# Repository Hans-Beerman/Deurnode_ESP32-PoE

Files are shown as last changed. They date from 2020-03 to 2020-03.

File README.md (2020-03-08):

**KiCaD (concept) design Deurnode nieuw**

Current version: concept V0.8

This repository contains the KiCad design for Deurnode nieuw, a deurnode for the Makerspace Leiden. This new design is based on the use of an Olimex ESP32-PoE.

**This Deurnode Nieuw has the following features:**

- Two digital inputs van be used. The following options are available:
	Option 1:
 	- 1x Simple digital switch input (to be used for the Grote Schakelaar e.g.).
 	- 1x Opto coupler input.
	Remark:
	If input Schakelaar is not used, C1 could be removed

	Option 2:
  - 2x opto coupler input.

	Both opto couplers can detect 230V AC available or not. By changing the input resistors of the optocouplers the inputs can be used for other voltages as well.

- 1 digital output is available. The following options are available:
  - Digital output, to directly control a buzzer.
  - Digital output to switch a coil or so. There are two options:
    - A relais controlled isolated output (max. 250V AC/10A).
    - A FET based output using the 12V power from an external power supply.
	The FET can handle max DC 55V/30 A. In our case max Ids is much less, due to to low maximum gateway voltage of about 3V. In case it is needed, the FET can be kept cool by means of a small cool block.
	For testing purposes, both the relais and the FET can be switched on permanently by placing jumper "Rel./FET Override".

- SPI based RFID reader connection..

- Step motor output, based on Polu Breakout A4988.

**Power supply:**

Depending on how the deurnode is used, there are two options to provide power to the deurnode print:

1. The ethernet port of the Olimex ESP32-PoE board is directly connected to the MSL LAN. Jumper J19 (Use external 12V) must be removed in this situation. In that case there is no 12V available. It is however possible to provide 12V with an external PSU. Without external 12 V the step motor and the buzzer will not function at all and also the 12V output for the FET will not be available.
2. To power the board via an external PSU (only). J19 must be installed and the ethernet board of the Olimex board should not be connected to a PoE switch port.

The following solution is available to couple the deurnode directly to a PoE connection of MSL LAN and also provide 12V to the deurnode board. See the diagram in the file &quot;Deurnode Nieuw power supply V0.1 20200302.pdf&quot;

For this solution a PoE splitter is used. On the Deurnode board jumper J19 must be installed.

**Protection 230V circuits for the opto couplers**

To prevent hazardous shocks, a plexiglass plate can be mounted on the board. The board contains 3 holes to mount a plate.

For more information about these protection plates, see the &quot;DeurnodeProtection-230V V0.2 20200308.pdf&quot; or the Autocad &quot;DeurnodeProtection-230V.dwg&quot; files.

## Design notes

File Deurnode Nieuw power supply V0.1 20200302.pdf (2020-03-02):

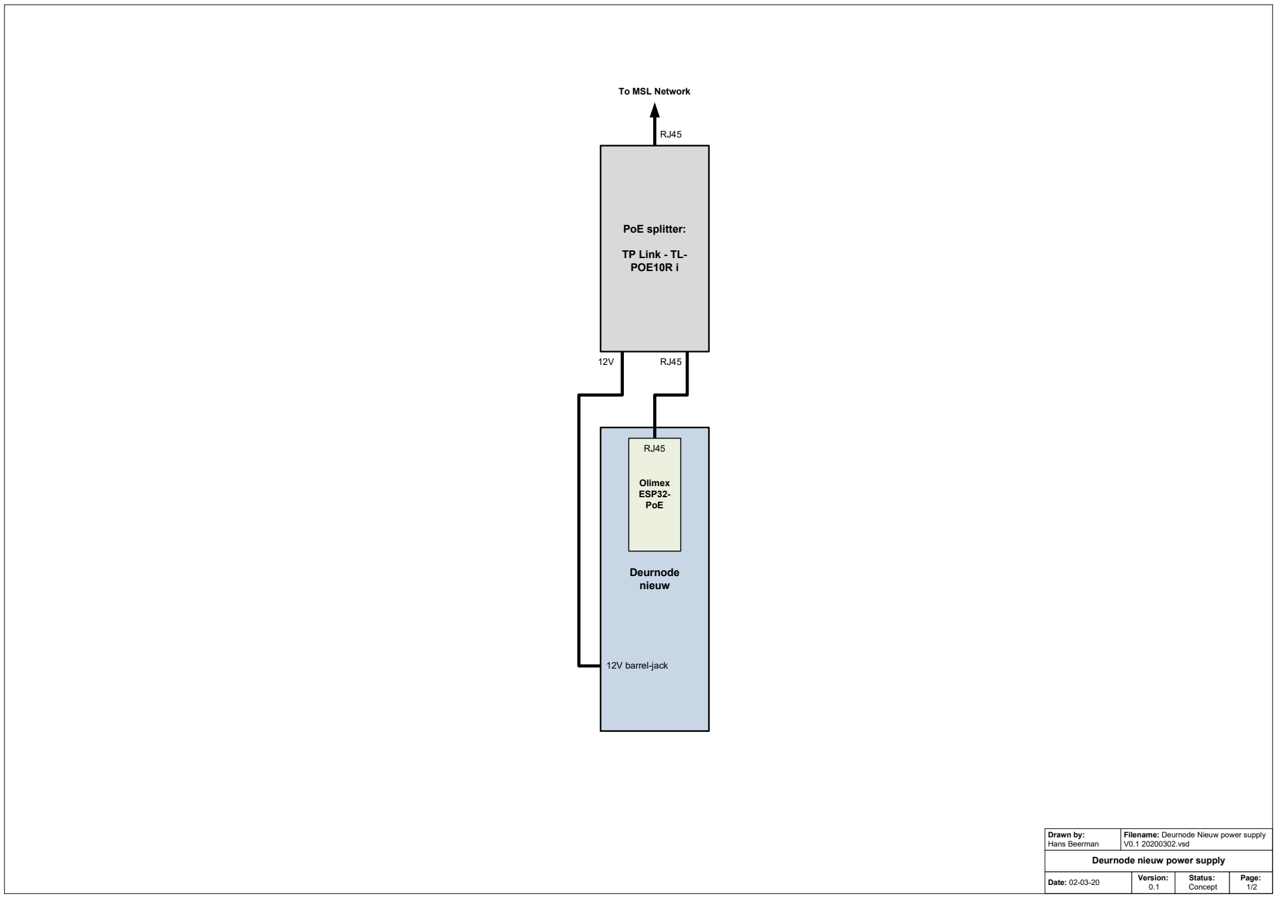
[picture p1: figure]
Deurnode nieuw power supply; Filename: Deurnode Nieuw power supply V0.1 20200302.vsd; Date: 02-03-20; Page:; Drawn by: Hans Beerman; Status: Concept; Version: 0.1; To MSL Network; Deurnode nieuw; Olimex ESP32- PoE; PoE splitter:; TP Link - TL- POE10R i; 12V barrel-jack

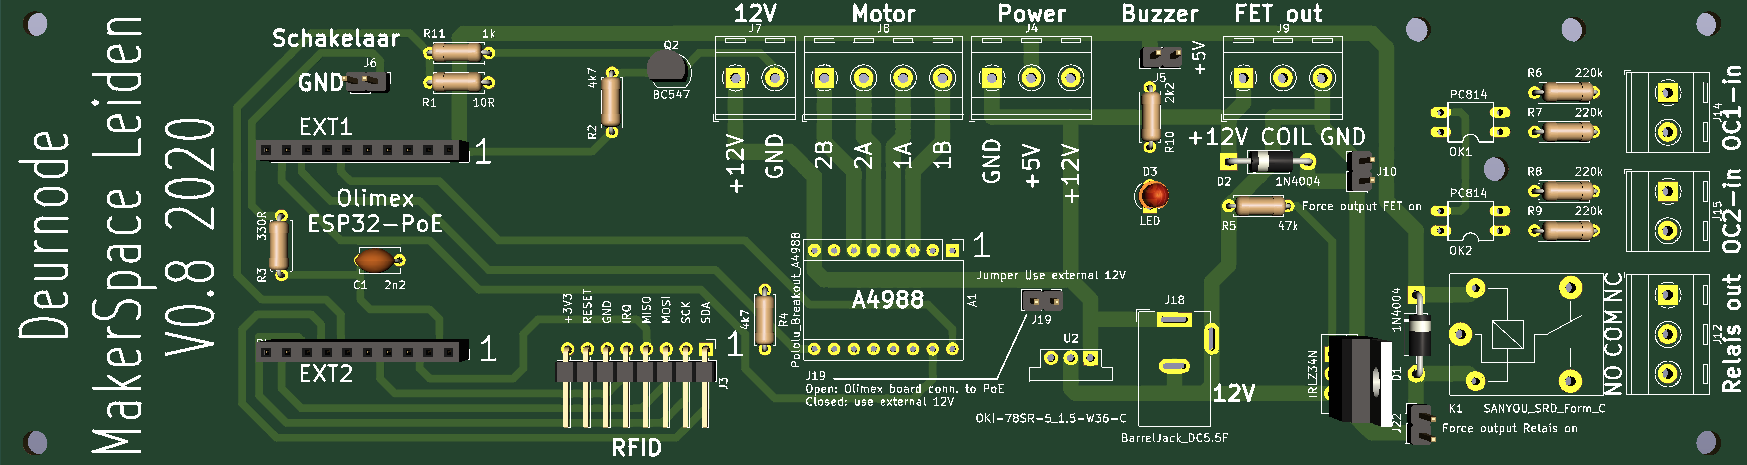
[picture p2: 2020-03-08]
Deurnode nieuw.png

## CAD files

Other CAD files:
DeurnodeProtection-230V V0.2 20200308.dwg

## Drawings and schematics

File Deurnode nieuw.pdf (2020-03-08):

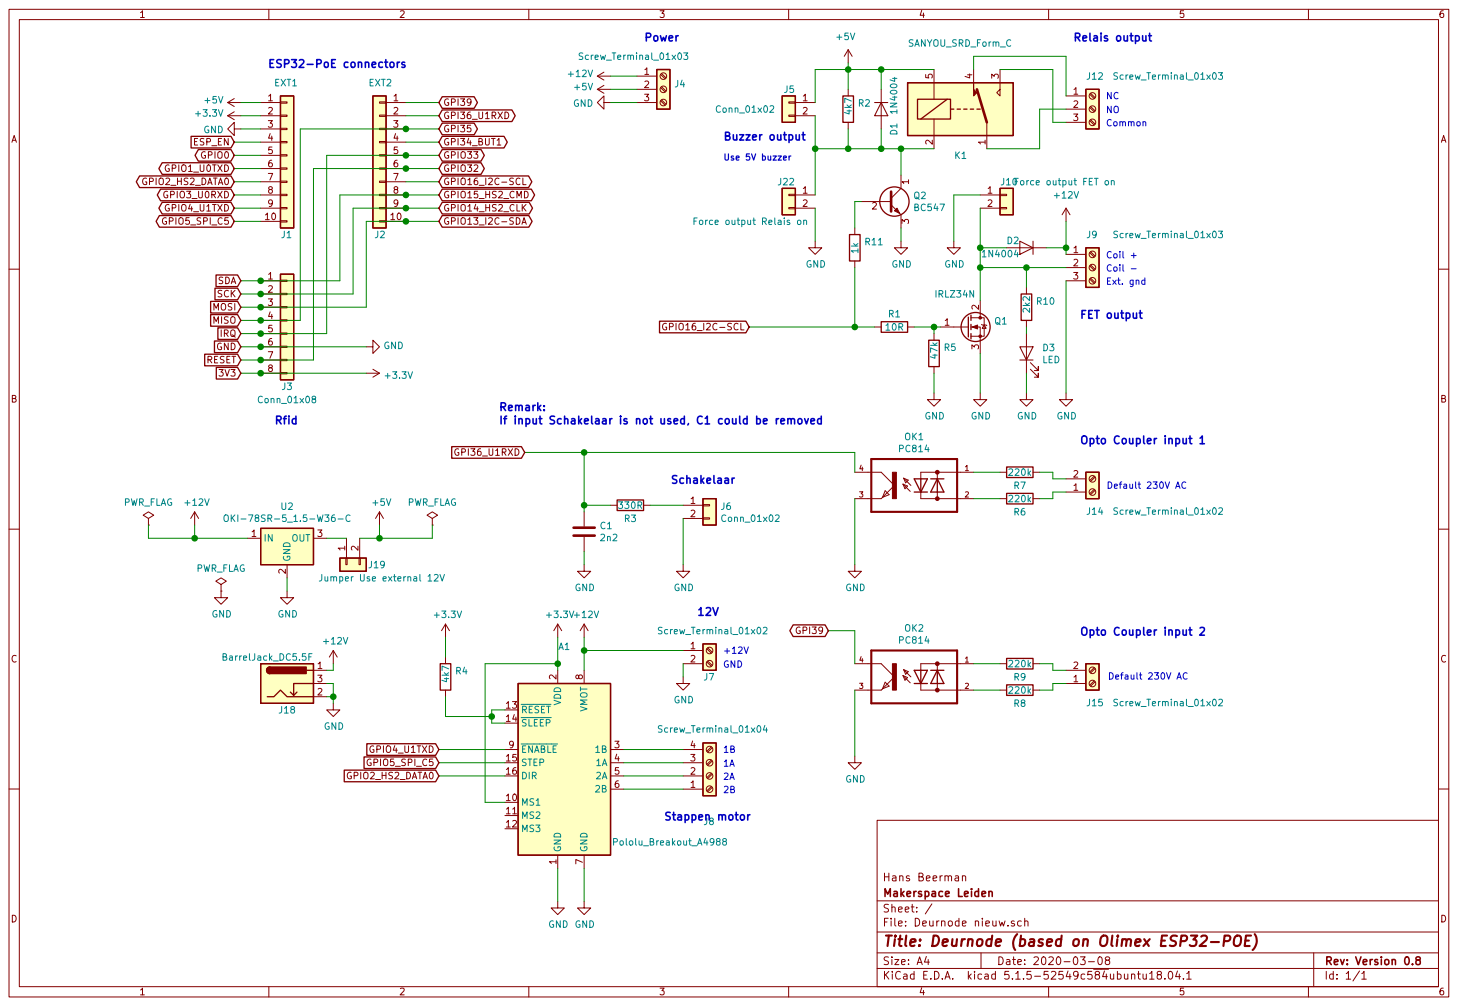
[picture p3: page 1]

J10 Force output FET on
Ext. gnd Default 230V AC

If input Schakelaar is not used, C1 could be removed

Id: 1/1 Title: Deurnode (based on Olimex ESP32-POE) File: Deurnode nieuw.sch Sheet: / Makerspace Leiden Hans Beerman R3

1 MS1 10 MS2 11 MS3 12 RESET 13 SLEEP 14 STEP 15 DIR 16 VDD

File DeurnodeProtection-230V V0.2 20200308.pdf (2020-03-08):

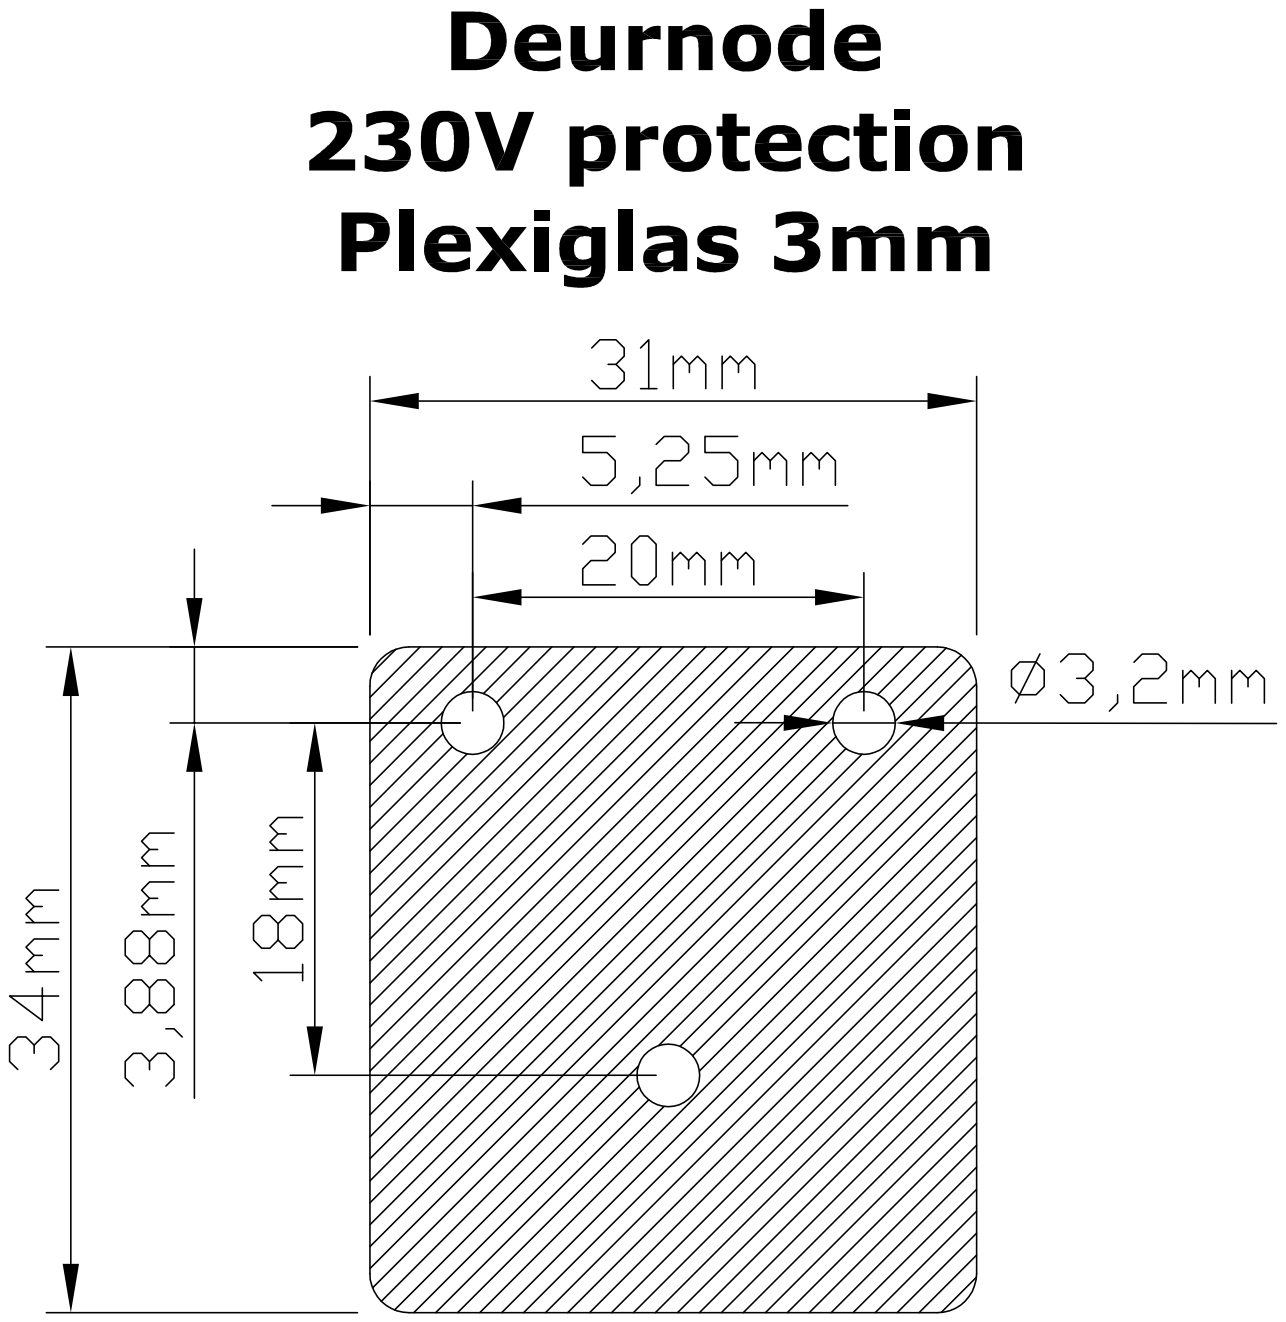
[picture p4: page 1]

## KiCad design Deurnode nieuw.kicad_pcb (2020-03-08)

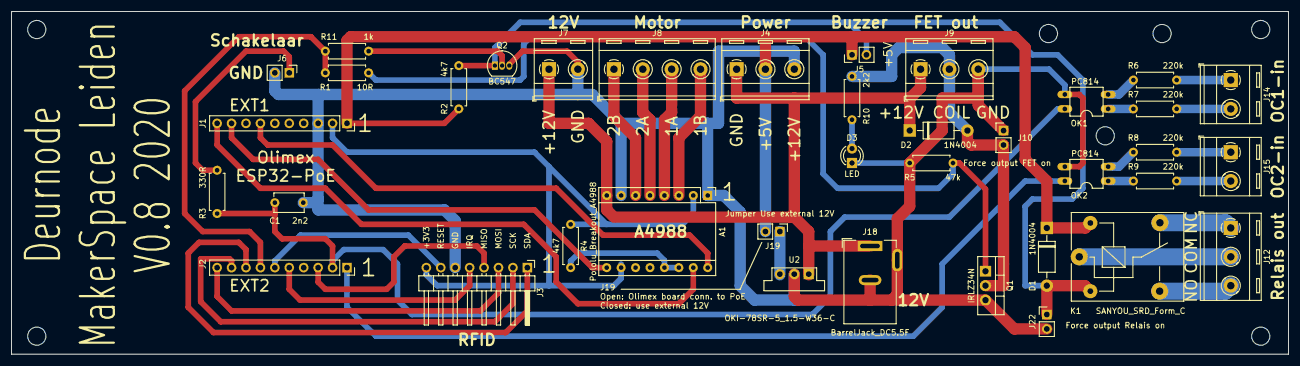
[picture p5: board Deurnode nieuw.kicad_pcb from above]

Board: 2 copper layers, 224.8 x 60.3 mm, 38 parts (0 on the bottom side), 39 nets.

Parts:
A1: Pololu_Breakout_A4988; Pololu_Breakout-16_15.2x20.3mm
C1: 2n2; C_Disc_D5.1mm_W3.2mm_P5.00mm
D1, D2: 1N4004; D_DO-41_SOD81_P10.16mm_Horizontal
D3: LED; LED_D3.0mm
J1: EXT1; PinSocket_1x10_P2.54mm_Vertical
J2: EXT2; PinSocket_1x10_P2.54mm_Vertical
J3: Conn_01x08; PinHeader_1x08_P2.54mm_Horizontal
J4, J9, J12: Screw_Terminal_01x03; TerminalBlock_RND_205-00288_1x03_P5.08mm_Horizontal
J5, J6: Conn_01x02; PinHeader_1x02_P2.54mm_Vertical
J7, J14, J15: Screw_Terminal_01x02; TerminalBlock_RND_205-00287_1x02_P5.08mm_Horizontal
J8: Screw_Terminal_01x04; TerminalBlock_RND_205-00289_1x04_P5.08mm_Horizontal
J10: Force output FET on; PinHeader_1x02_P2.54mm_Vertical
J18: BarrelJack_DC5.5F
J19: Jumper Use external 12V; PinHeader_1x02_P2.54mm_Vertical
J22: Force output Relais on; PinHeader_1x02_P2.54mm_Vertical
K1: SANYOU_SRD_Form_C; Relay_SPDT_SANYOU_SRD_Series_Form_C
OK1, OK2: PC814; DIL04
Q1: IRLZ34N; TO-220-3_Vertical
Q2: BC547; TO-92_Inline
R1: 10R; R_Axial_DIN0207_L6.3mm_D2.5mm_P7.62mm_Horizontal
R2, R4: 4k7; R_Axial_DIN0207_L6.3mm_D2.5mm_P7.62mm_Horizontal
R3: 330R; R_Axial_DIN0207_L6.3mm_D2.5mm_P7.62mm_Horizontal
R5: 47k; R_Axial_DIN0207_L6.3mm_D2.5mm_P7.62mm_Horizontal
R6, R7, R8, R9: 220k; R_Axial_DIN0207_L6.3mm_D2.5mm_P7.62mm_Horizontal
R10: 2k2; R_Axial_DIN0207_L6.3mm_D2.5mm_P7.62mm_Horizontal
R11: 1k; R_Axial_DIN0207_L6.3mm_D2.5mm_P7.62mm_Horizontal
U2: OKI-78SR-5_1.5-W36-C; Converter_DCDC_muRata_OKI-78SR_Vertical

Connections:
3V3: A1.2, A1.10, J1.2, J3.8, R4.1
+5V: D1.1, J1.1, J4.2, J5.1, J19.2, K1.5, R2.1
+12V: A1.8, D2.1, J4.1, J7.1, J9.1, J18.1, U2.1
GND: A1.1, A1.7, C1.2, D3.1, J1.3, J3.6, J4.3, J6.2, J7.2, J9.3, J10.1, J18.2, J18.3, J22.2, OK1.3, OK2.3, Q1.3, Q2.3, R5.2, U2.2
GPI35: J2.3, J3.4
GPI36_U1RXD: C1.1, J2.2, OK1.4, R3.2
GPI39: J2.1, OK2.4
GPIO2_HS2_DATA0: A1.16, J1.7
GPIO4_U1TXD: A1.9, J1.9
GPIO5_SPI_C5: A1.15, J1.10
GPIO13_I2C-SDA: J2.10, J3.3
GPIO14_HS2_CLK: J2.9, J3.2
GPIO15_HS2_CMD: J2.8, J3.1
GPIO16_I2C-SCL: J2.7, R1.2, R11.2
GPIO32: J2.6, J3.7
GPIO33: J2.5, J3.5
unnamed: A1.3, J8.4
unnamed: A1.4, J8.3
unnamed: A1.5, J8.2
unnamed: A1.6, J8.1
unnamed: A1.13, A1.14, R4.2
unnamed: D1.2, J5.2, J22.1, K1.2, Q2.1, R2.2
unnamed: D2.2, J9.2, J10.2, Q1.2, R10.1
unnamed: D3.2, R10.2
unnamed: J6.1, R3.1
unnamed: J12.1, K1.4
unnamed: J12.2, K1.1
unnamed: J12.3, K1.3
unnamed: J14.1, R6.1
unnamed: J14.2, R7.1
unnamed: J15.1, R8.1
unnamed: J15.2, R9.1
unnamed: J19.1, U2.3
unnamed: OK1.1, R7.2
unnamed: OK1.2, R6.2
unnamed: OK2.1, R9.2
unnamed: OK2.2, R8.2
unnamed: Q1.1, R1.1, R5.1
unnamed: Q2.2, R11.1

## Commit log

2020-02-27 First publisched concept version
    [Deurnode nieuw.kicad_pcb, Deurnode nieuw.sch]
2020-02-28 Second publisched concept version
    [Deurnode nieuw.sch]
2020-02-28 Second publisched concept version + schematics pdf
    [Deurnode nieuw.sch]
2020-03-02 DC-DC converter 12V -> 5V added to concept version 0.3
    [Deurnode nieuw.kicad_pcb, Deurnode nieuw.sch]
2020-03-02 README.md and other docs added, additional 12V connector added to design concept version 0.4
    [Deurnode nieuw.kicad_pcb, Deurnode nieuw.sch, DeurnodeProtection-230V.dwg]
2020-03-02 Replaced old version of Deurnode nieuw.pdf, still on concept version 0.4
    [Deurnode nieuw.sch]
2020-03-03 By means of two jumpers the FET components are isolated from the rest of the board. Current concept version 0.5
    [Deurnode nieuw.kicad_pcb, Deurnode nieuw.sch]
2020-03-05 Jumper added for Relais/FET override + correct footprint made for 12V barel jack current version concept V0.6
    [Deurnode nieuw.kicad_pcb, Deurnode nieuw.sch]
2020-03-06 Readme.md pdated to reflect changes in current concept version 0.6
2020-03-08 removed a lot of jumpers, replaced connectors, added groundplane etc.
    [Deurnode nieuw.kicad_pcb, Deurnode nieuw.sch, DeurnodeProtection-230V V0.2 20200308.dwg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]
2020-03-08 Relais and FET are controlled separately, buzzer resistor added. Current version Concep V0.8
    [Deurnode nieuw.kicad_pcb, Deurnode nieuw.sch]
